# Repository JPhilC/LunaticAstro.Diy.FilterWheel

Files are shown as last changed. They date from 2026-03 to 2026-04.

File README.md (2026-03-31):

## An Arduino Nano controlled 3D printed filterwheel for astronomy.

This project was inspired by, and builds, on the work of chemistorge who's original repo can be found [here](https://github.com/chemistorge/Arduino-Motorised-Filter-Wheel-Xagyl-compatible-ASCOM-and-INDI-).

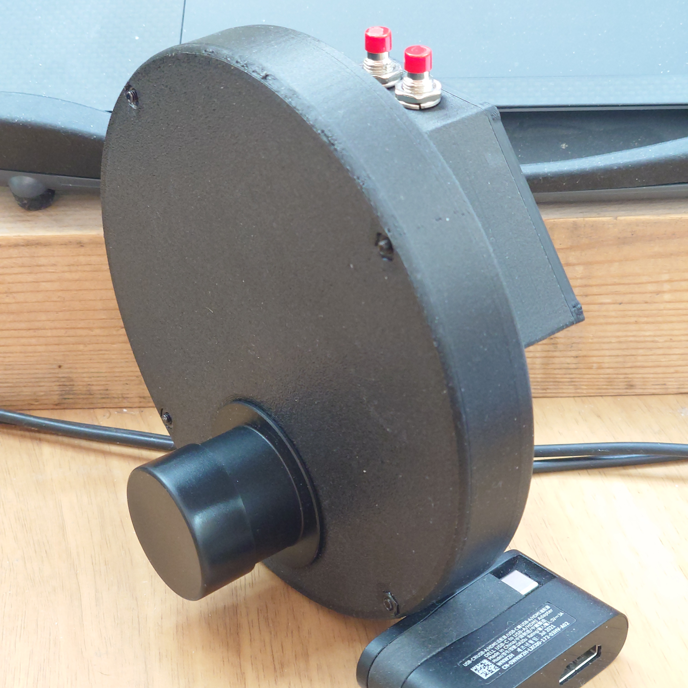
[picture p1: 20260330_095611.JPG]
Picture of front of filter wheel
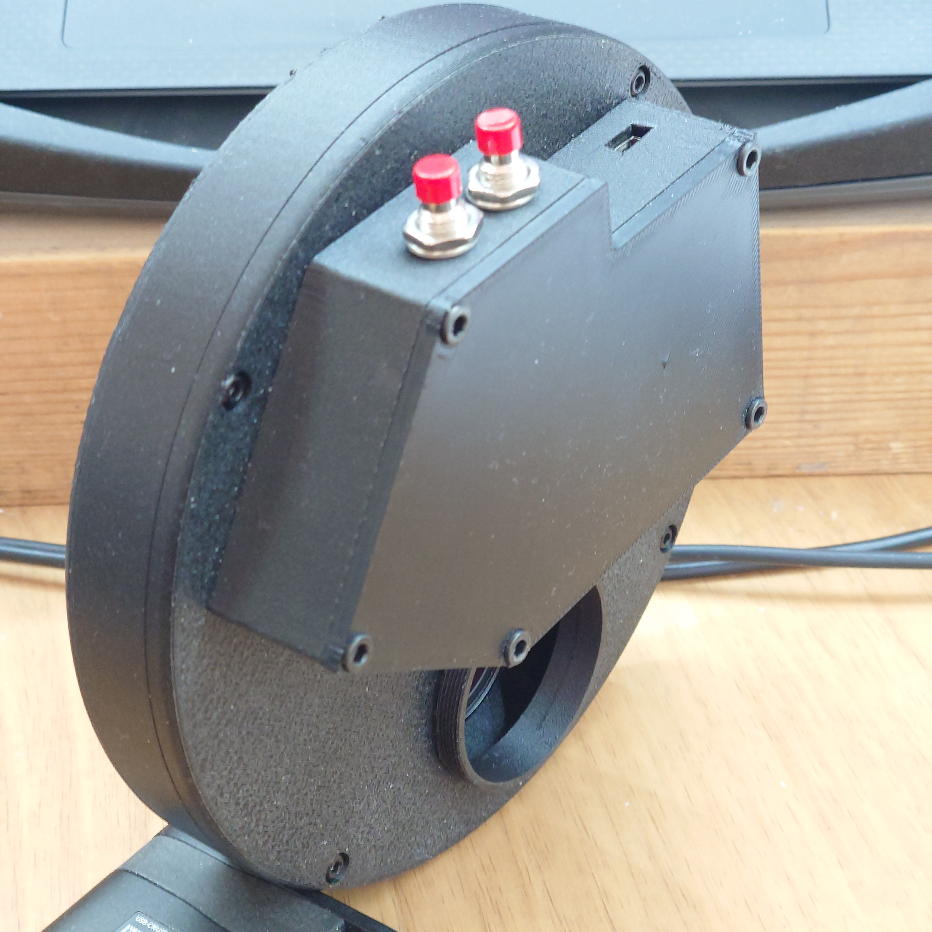
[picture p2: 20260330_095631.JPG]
Picture of back of filter wheel
|  |  |
|---|---|

After printing the parts I struggled to get the original firmware to operate reliably so I wrote new firmware, roughly based on the original but with improved home detection and button de-bounce code. I also changed the command set to make it more compatible with a new ASCOM driver that is also included in this project meaning that **the new firmware is not compatible with the old Xagly ASCOM driver**.

The firmware has only been tested with a unipolar 28BYJ-48 stepper motor, the common ULN2003 driver board and a KY-003 analogue hall sensor.

The original Xagly ASCOM driver appears not be supported or further developed so I wrote a new ASCOM driver that is better suited to the capabilities of the hardware.

The Ardiuno sketch is in the Firmware folder and the ASCOM source code is in the ASCOM Driver folder. 

The ASCOM drive passes ASCOMs Universal Conform tool and a log of the results is included in the ASCOM driver folder.

I printed my filter wheel parts in Sunlu PEG-CF on a Bambu A1 and will only be attaching my small ASI678 panetary camera.

## Disclaimer

The firmware and software in this project is provided “as is”, without warranty of any kind, express or implied.
The author shall not be held liable for any damages, loss of data, hardware damage,
or any other issues arising from the use of this software. Use at your own risk.
3D printed components can be weak along the layer lines so be sensible about what equipment you attach to the filter wheel.

## License

This project is licensed under the Creative Commons Attribution–NonCommercial 4.0 International License (CC BY-NC 4.0).

You may use, modify, and share the code for non-commercial purposes, provided you give appropriate credit.
Commercial use is strictly prohibited.

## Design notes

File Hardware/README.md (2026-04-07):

The hardware for this project is the same as [Arduino-Motorised-Filter-Wheel-Xagyl-compatible-ASCOM-and-INDI-](https://github.com/chemistorge/Arduino-Motorised-Filter-Wheel-Xagyl-compatible-ASCOM-and-INDI-). 

Rather than copying the details here, please refer to the original project for the original print files and also for details of the electrical components. 

## Important

The firmware in this project expects the following Arduino Nano pin outs:
### Analogue pins
- A1 - Hall sensor (common -)
- A2 - Hall sensor (power (centre pin on sensor))
- A3 - Hall sensor (sensor S)
### Digital pins
- 10 LED
- 4 Up button
- 5 Down button
- 6 Stepper IN2
- 7 Stepper IN4
- 8 Stepper IN3
- 9 Stepper IN1

## The Hall Sensor
The firmware has only been tested with a KY-003 analogue hall sensor. This is the one I used. This is the one I used [KY-003 Hall Effect Magnetic Sensor Module For Arduino](https://www.ebay.co.uk/itm/303361490827)

## Wiring internals
The image below shows the wiring and electronics prior to an LED being added.

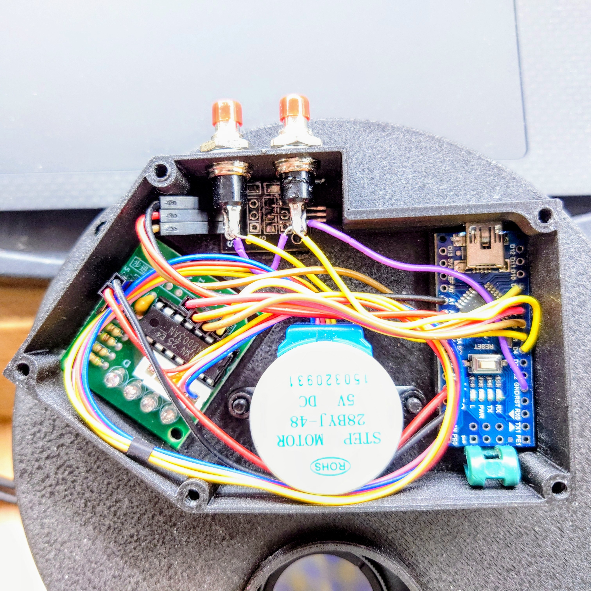
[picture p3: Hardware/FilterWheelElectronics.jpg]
Wiring internals


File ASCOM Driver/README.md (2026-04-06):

An ASCOM Driver for the Lunatic Astro DIY Filterwheel.

## The latest version of the ASCOM Driver
[**⬇️ Download Lunatic Astro Nano Filterwheel ASCOM Driver (MSI)**](./LunaticAstro.Nano.FilterWheel.Driver_V1.0.0.msi)

## Disclaimer
This software is provided “as is”, without warranty of any kind, express or implied. 
The author shall not be held liable for any damages, loss of data, hardware damage, 
or any other issues arising from the use of this software. Use at your own risk.

## License
This project is licensed under the Creative Commons Attribution–NonCommercial 4.0 International License (CC BY-NC 4.0).

You may use, modify, and share the code for non-commercial purposes, provided you give appropriate credit.
Commercial use is strictly prohibited.

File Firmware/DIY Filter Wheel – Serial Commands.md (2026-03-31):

# DIY Filter Wheel – Serial Command Reference
**Protocol Version 1.0**  
Compatible with Xagyl-style ASCOM drivers

This document describes the serial command protocol implemented by the DIY Filter Wheel firmware.  
The command set is intentionally compatible with the legacy Xagyl filter wheel protocol so that existing Xagyl ASCOM drivers can communicate with the device.

Commands fall into two categories:

- **Supported Commands** — These control real hardware behaviour.  
- **Spoofed Commands** — These return fixed or simulated values for Xagyl driver compatibility.  
  *(These may be removed or replaced when the custom ASCOM driver is complete.)*

---

# 1. Movement Commands

## **G1 .. G8 — Go To Filter Position**
**Syntax:** `Gn`  
Moves the wheel to filter position *n*.  
Filter **1** triggers a full homing cycle.

**Response:**
```text
P<n>
```

---

## **G0 — Save Configuration**
Saves all configuration settings (offsets, speed, etc.) to EEPROM.

**Response:**
```text
EEPROM Saved
```

---

# 2. Offset Commands

## **O1 .. O8 — Query Offset for Filter**
**Syntax:** `On`  
Returns the stored offset for filter *n*.

**Response:**
```text
P<n> Offset X
```

---

## **Fn xxxx — Set Positional Offset**
**Syntax:** `F<n> <number>`  
Sets the position offset for the filter in position `<n>` to an explicit value `<number>`. This allows you to centeralise the filter position in the filter wheel opening.  
Triggers a re-home and re-position.

**Response:**
```text
P<n> Offset X
```

---

# 3. Information Commands (Supported)

These map directly to `handleInfo(char c1)`.

## **I0 — Product Name**
**Response:**
```text
Nano Filter Wheel
```

---

## **I1 — Firmware Version**
**Response:**
```text
FW1.0.0
```

---

## **I2 — Current Filter Position**
**Response:**
```text
P<n>
```

---

## **I3 — Serial Number**
**Response:**
```text
DIY
```

---

## **I4 — Maximum Speed**
**Response:**
```text
MaxSpeed <maxSpeed>
```

---

## **I5 — Current Filter Offset**
**Response:**
```text
P<n> Offset X
```

---

## **I6 — Threshold**
**Response:**
```text
Threshold <analogSensorThreshold>
```

---

## **I7 — Number of Filter Slots**
**Response:**
```text
FilterSlots <numberOfFilters>
```

---

# 4. Sensor Test Commands

These map to `handleSensorTest(char c1)`.

## **T0 / T1 — Sensor Digital State**
**Response:**
```text
Sensors <state> <state>
```

---

## **T2 — Sensor Type**
**Response:**
```text
Digital YES
```
or
```text
Digital NO
```

---

## **T3 — Sensor Polarity**
**Response:**
```text
Active High YES
```
or
```text
Active High NO
```

---

# 5. Reset / Calibration Commands

These map to `handleReset(char c1)`.

## **R1 — Re-Initialise**
Re-initialises the wheel (calls `initialise()`).

---

## **R2 — Reset All Offsets**
Clears all offsets, saves configuration, and re-homes.

**Response:**
```text
Calibration Removed
```

---

## **R3 — Reset Speed to 100%**
**Response:**
```text
MaxSpeed 100%
```

---

## **R4 — Re-Detect Sensor and Re-Initialise**
**Response:**
```text
Threshold <analogSensorThreshold>
```

---

# 6. Speed Commands

## **Sxxx — Set Rotation Speed**
**Syntax:** `S<number>`  
Sets speed as a percentage of maximum.

**Response:**
```text
MaxSpeed <percent>%
```

---

## **T0 .. T3 — Sensor Test **
Returns values.

---

# 8. Unknown Commands
Unknown commands are silently ignored.

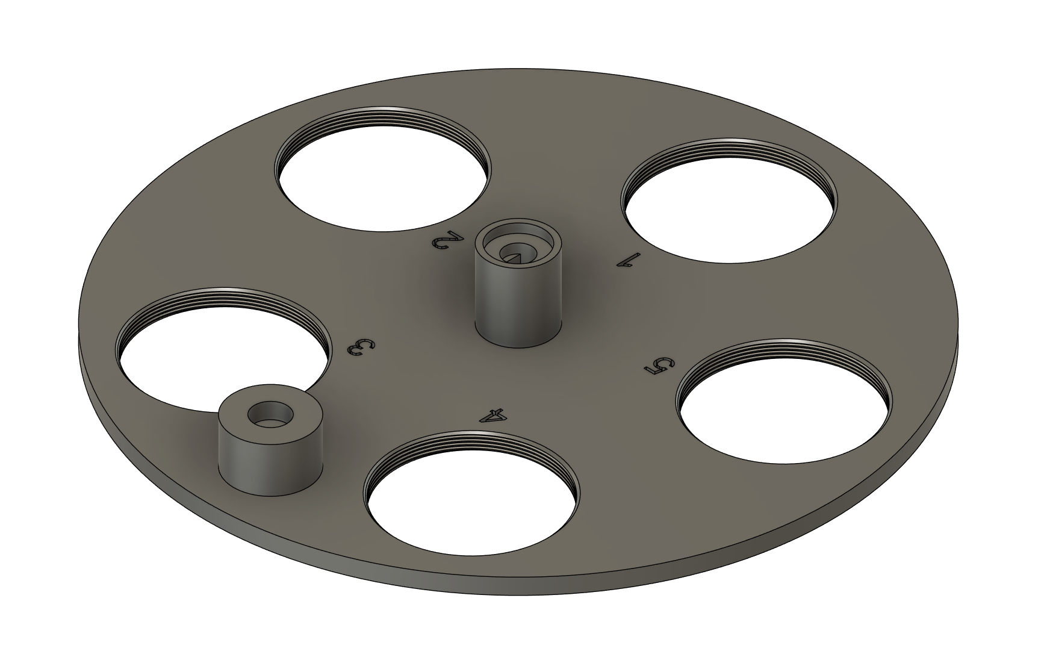
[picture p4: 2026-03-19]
Hardware/Wheel.png

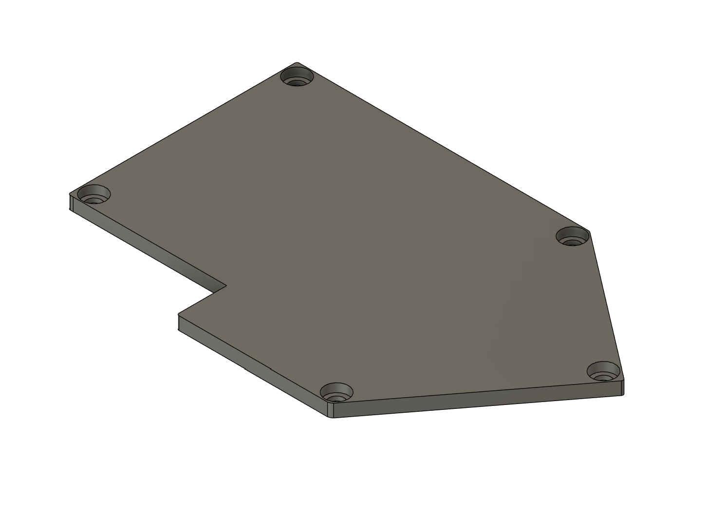
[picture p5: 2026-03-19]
Hardware/Cover.png

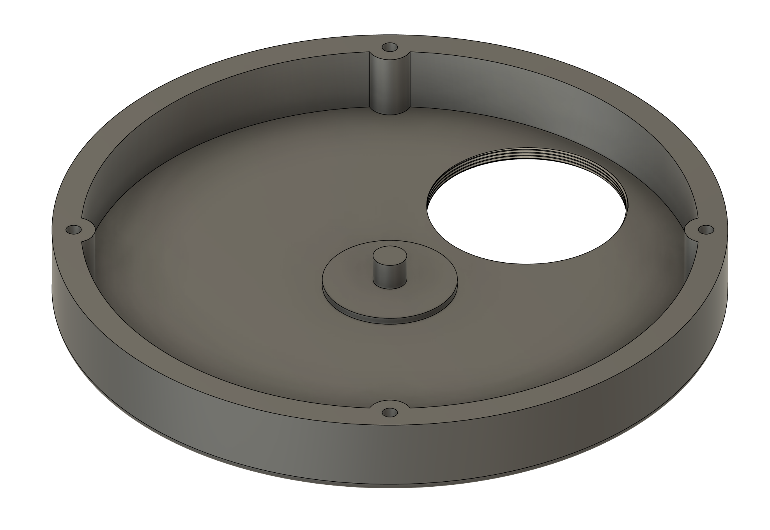
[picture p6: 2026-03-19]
Hardware/Bottom.png

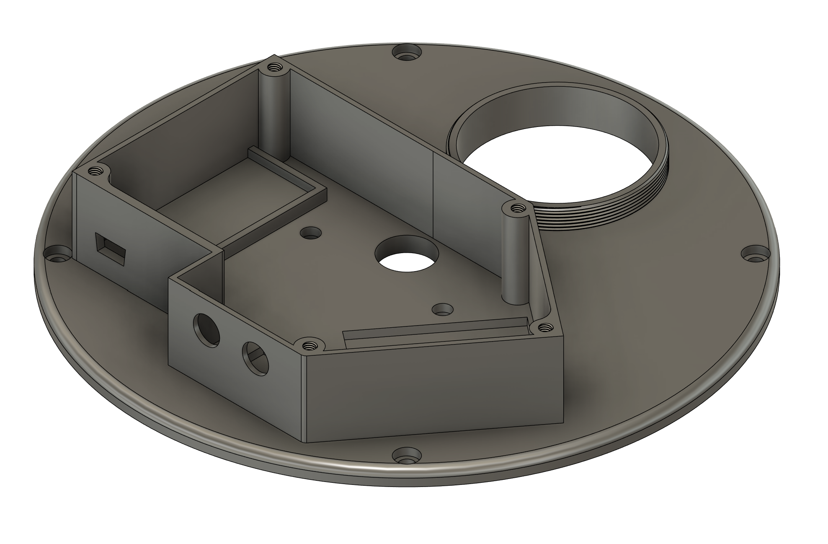
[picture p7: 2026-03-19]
Hardware/Top.png

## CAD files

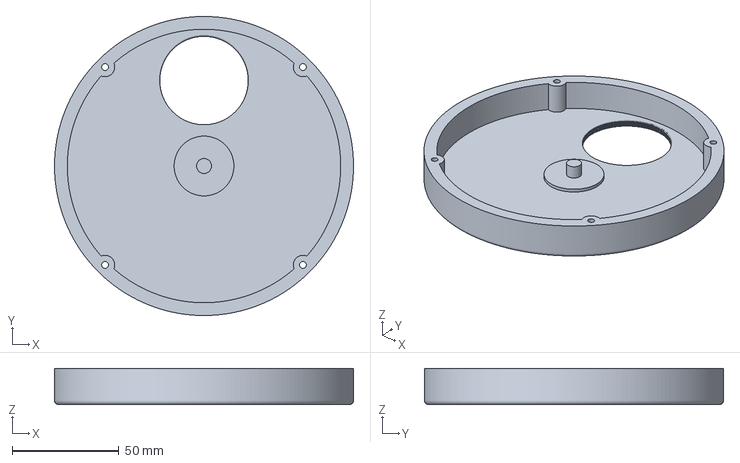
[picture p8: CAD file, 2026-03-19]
Hardware/Print Files/Bottom.3mf
140.0 x 140.0 x 17.0 mm

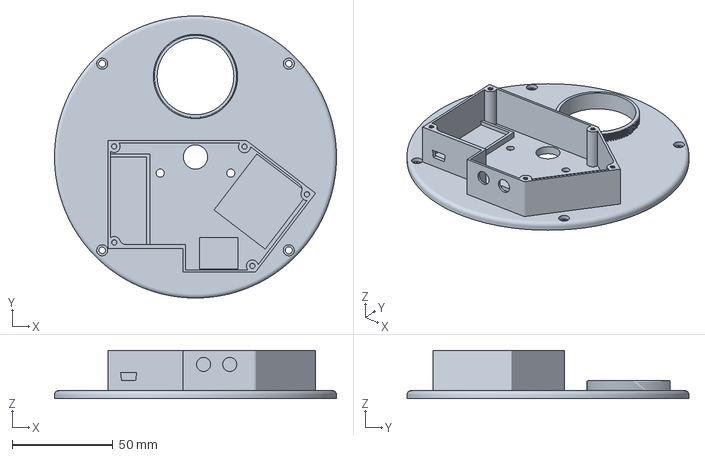
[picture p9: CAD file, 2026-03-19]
Hardware/Print Files/Top.3mf
140.0 x 140.0 x 24.0 mm

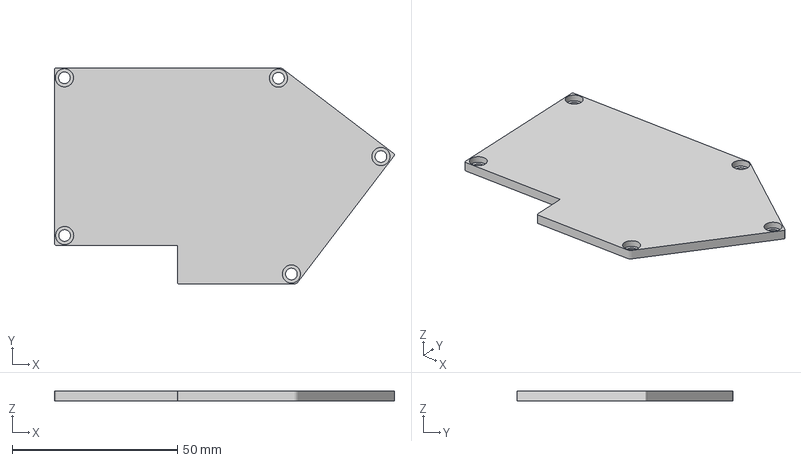
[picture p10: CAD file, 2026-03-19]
Hardware/Print Files/Cover.3mf
102.8 x 65.4 x 3.00 mm

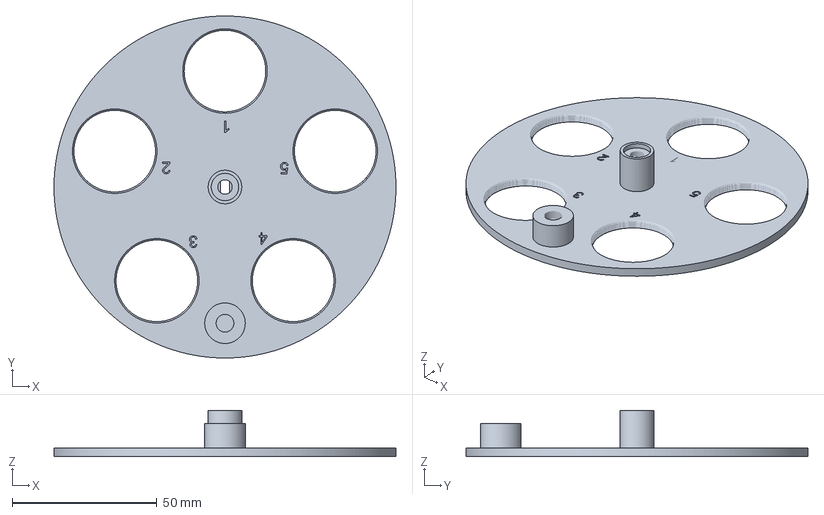
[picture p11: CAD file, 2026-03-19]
Hardware/Print Files/Wheel.3mf
118.0 x 118.0 x 16.0 mm

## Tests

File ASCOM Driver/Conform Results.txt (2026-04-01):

09:37:13.653 ASCOM Universal Device Conformance Checker Version 4.2.1.48140, Build time: Mon 09 February 2026 12:14:24
09:37:13.653 
09:37:13.654 Operating system is Windows 11 (25H2), Processor is Intel/AMD 64bit, Application is 64bit.
09:37:13.654 
09:37:13.654 COM Driver ProgID: ASCOM.LunaticAstroDiyFilterWheel.FilterWheel
09:37:13.654 
09:37:13.654 CreateDevice                        INFO     Creating NATIVE COM device: ASCOM.LunaticAstroDiyFilterWheel.FilterWheel
09:37:13.881 CreateDevice                        INFO     Successfully created driver
09:37:14.905 CreateDevice                        OK       Found a valid interface version: 3
09:37:14.906 CreateDevice                        OK       Driver instance created successfully
09:37:14.906 
09:37:14.906 Connect to device
09:37:16.427 Connected                           OK       Connected to device successfully using Connected = True
09:37:16.948 Connected                           OK       Disconnected from device successfully using Connected = False
09:37:18.964 Connect                             OK       Connected to device successfully using Connect()
09:37:18.964 
09:37:18.964 Common Driver Methods
09:37:18.964 InterfaceVersion                    OK       3
09:37:18.965 Connected                           OK       True
09:37:18.966 Description                         OK       Lunatic Astro Nano Filter Wheel
09:37:18.968 DriverInfo                          OK       Information about the driver itself. Version: 7.0
09:37:18.969 DriverVersion                       OK       7.0
09:37:18.969 Name                                OK       Lunatic Astro Nano Filter Wheel
09:37:18.969 
09:37:18.970 Action                              INFO     Conform cannot test the Action method
09:37:18.996 SupportedActions                    OK       Driver returned an empty action list
09:37:18.996 
09:37:19.006 DeviceState                         OK       Received 2 operational state properties.
09:37:19.007 DeviceState                         OK         Position = -1
09:37:19.007 DeviceState                         OK         TimeStamp = 01/04/2026 09:37:18
09:37:19.008 DeviceState                         OK       Found all expected operational properties
09:37:19.008 
09:37:19.008 Pre-run Checks
09:37:25.160 Pre-run Check                       OK       Filter wheel is stationary, ready to start tests
09:37:25.161 
09:37:25.161 Properties
09:37:25.162 FocusOffsets Get                    OK       Found 5 filter offset values
09:37:25.163 FocusOffsets Get                    INFO     Filter 0 Offset: 0
09:37:25.163 FocusOffsets Get                    INFO     Filter 1 Offset: 0
09:37:25.163 FocusOffsets Get                    INFO     Filter 2 Offset: 0
09:37:25.163 FocusOffsets Get                    INFO     Filter 3 Offset: 0
09:37:25.163 FocusOffsets Get                    INFO     Filter 4 Offset: 20
09:37:25.164 Names Get                           OK       Found 5 filter names
09:37:25.164 Names Get                           INFO     Filter 0 Name: Luminesence
09:37:25.164 Names Get                           INFO     Filter 1 Name: Red
09:37:25.164 Names Get                           INFO     Filter 2 Name: Green
09:37:25.165 Names Get                           INFO     Filter 3 Name: Blue
09:37:25.165 Names Get                           INFO     Filter 4 Name: <unused>
09:37:25.165 Names Get                           OK       Number of filter offsets and number of names are the same: 5
09:37:25.165 Position Get                        OK       Currently at position: 1
09:37:25.166 
09:37:25.166 Testing ascending sequential movement
09:37:25.285 Position Set 0                      OK       Reached position: 0 in: 0.1 seconds
09:37:27.719 Position Set 1                      OK       Reached position: 1 in: 1.4 seconds
09:37:30.137 Position Set 2                      OK       Reached position: 2 in: 1.4 seconds
09:37:32.557 Position Set 3                      OK       Reached position: 3 in: 1.4 seconds
09:37:34.985 Position Set 4                      OK       Reached position: 4 in: 1.4 seconds
09:37:36.000 
09:37:36.000 Testing descending sequential movement
09:37:36.113 Position Set 4                      OK       Reached position: 4 in: 0.1 seconds
09:37:39.942 Position Set 3                      OK       Reached position: 3 in: 2.8 seconds
09:37:43.663 Position Set 2                      OK       Reached position: 2 in: 2.7 seconds
09:37:47.493 Position Set 1                      OK       Reached position: 1 in: 2.8 seconds
09:37:51.310 Position Set 0                      OK       Reached position: 0 in: 2.8 seconds
09:37:52.322 
09:37:52.322 Testing potentially long distance moves
09:37:52.435 Position Set 0                      OK       Reached position: 0 in: 0.1 seconds
09:37:57.959 Position Set 4                      OK       Reached position: 4 in: 4.5 seconds
09:38:01.791 Position Set 3                      OK       Reached position: 3 in: 2.8 seconds
09:38:07.622 Position Set 0                      OK       Reached position: 0 in: 4.8 seconds
09:38:11.142 Position Set 2                      OK       Reached position: 2 in: 2.5 seconds
09:38:15.973 Position Set 0                      OK       Reached position: 0 in: 3.8 seconds
09:38:16.979 
09:38:16.979 Testing error conditions
09:38:17.009 Position Set                        OK       Correctly rejected bad position: -1
09:38:17.011 Position Set                        OK       Correctly rejected bad position: 5
09:38:17.011 
09:38:17.011 Directionality assessment
09:38:17.012 Directionality                      INFO     The filter wheel is uni-directional.
09:38:17.012 
09:38:17.012 Disconnect from device
09:38:17.526 Disconnect                          OK       Disconnected from device successfully using Disconnect()
09:38:17.526 
09:38:17.526 Conformance test has finished
09:38:17.526 
09:38:17.526 Congratulations, no errors, warnings or issues found: your driver passes ASCOM validation!!
09:38:17.526  
09:38:17.526 Timing Summary                               See Help for further information.
09:38:17.527 Timing Summary                               FAST target response time: 0.1 seconds, (configuration and state reporting members).
09:38:17.527 Timing Summary                               STANDARD target response time: 1.0 second, (property write and asynchronous initiators).
09:38:17.527 Timing Summary                               EXTENDED target response time: 600.0 seconds, (synchronous methods, ImageArray and ImageArrayVariant).
09:38:17.527 Timing Summary                               Conform is configured to report both good and bad timing outcomes.
09:38:17.527 
09:38:17.527 Connect                                      At 09:37:16.948 Connect                  0.001 seconds. ✓ (STANDARD)
09:38:17.527 InterfaceVersion                             At 09:37:18.964 InterfaceVersion         0.000 seconds. ✓ (FAST)
09:38:17.527 Connected                                    At 09:37:18.965 Connected                0.000 seconds. ✓ (FAST)
09:38:17.527 Description                                  At 09:37:18.966 Description              0.001 seconds. ✓ (FAST)
09:38:17.528 DriverInfo                                   At 09:37:18.967 DriverInfo               0.001 seconds. ✓ (FAST)
09:38:17.528 DriverVersion                                At 09:37:18.969 DriverVersion            0.001 seconds. ✓ (FAST)
09:38:17.528 Name                                         At 09:37:18.969 Name                     0.000 seconds. ✓ (FAST)
09:38:17.528 SupportedActions                             At 09:37:18.996 SupportedActions         0.026 seconds. ✓ (FAST)
09:38:17.528 DeviceState                                  At 09:37:19.006 DeviceState              0.010 seconds. ✓ (FAST)
09:38:17.528 FocusOffsets                                 At 09:37:25.162 FocusOffsets             0.001 seconds. ✓ (FAST)
09:38:17.528 Names                                        At 09:37:25.164 Names                    0.001 seconds. ✓ (FAST)
09:38:17.528 Position                                     At 09:37:25.165 Position                 0.001 seconds. ✓ (FAST)
09:38:17.528 Move to position 0                           At 09:37:25.172 Move to position 0       0.006 seconds. ✓ (STANDARD)
09:38:17.528 Move to position 1                           At 09:37:26.300 Move to position 1       0.002 seconds. ✓ (STANDARD)
09:38:17.529 Move to position 2                           At 09:37:28.733 Move to position 2       0.002 seconds. ✓ (STANDARD)
09:38:17.529 Move to position 3                           At 09:37:31.151 Move to position 3       0.001 seconds. ✓ (STANDARD)
09:38:17.529 Move to position 4                           At 09:37:33.567 Move to position 4       0.001 seconds. ✓ (STANDARD)
09:38:17.529 Move to position 4                           At 09:37:36.001 Move to position 4       0.001 seconds. ✓ (STANDARD)
09:38:17.529 Move to position 3                           At 09:37:37.125 Move to position 3       0.002 seconds. ✓ (STANDARD)
09:38:17.529 Move to position 2                           At 09:37:40.954 Move to position 2       0.001 seconds. ✓ (STANDARD)
09:38:17.529 Move to position 1                           At 09:37:44.675 Move to position 1       0.001 seconds. ✓ (STANDARD)
09:38:17.529 Move to position 0                           At 09:37:48.505 Move to position 0       0.001 seconds. ✓ (STANDARD)
09:38:17.530 Move to position 0                           At 09:37:52.323 Move to position 0       0.001 seconds. ✓ (STANDARD)
09:38:17.530 Move to position 4                           At 09:37:53.445 Move to position 4       0.002 seconds. ✓ (STANDARD)
09:38:17.530 Move to position 3                           At 09:37:58.977 Move to position 3       0.001 seconds. ✓ (STANDARD)
09:38:17.530 Move to position 0                           At 09:38:02.802 Move to position 0       0.001 seconds. ✓ (STANDARD)
09:38:17.530 Move to position 2                           At 09:38:08.627 Move to position 2       0.001 seconds. ✓ (STANDARD)
09:38:17.530 Move to position 0                           At 09:38:12.157 Move to position 0       0.001 seconds. ✓ (STANDARD)
09:38:17.530 Disconnect                                   At 09:38:17.013 Disconnect               0.001 seconds. ✓ (STANDARD)
09:38:17.530 
09:38:17.530 Congratulations, all members returned within their target response times!!

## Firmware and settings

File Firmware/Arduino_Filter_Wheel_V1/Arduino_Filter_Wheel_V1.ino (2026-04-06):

#include <AccelStepper.h>
#include <EEPROM.h>

/* ==========================================================================  
   Lunatic Astro Filter Wheel Firmware  
   Copyright © 2026 Phil Crompton, Lunatic Astro  
   All rights reserved.

   This firmware is provided for use with Lunatic Astro hardware projects.  
   Redistribution or modification is permitted only with explicit permission  
   from the copyright holder.

   For project information, updates, and documentation, visit Lunatic Astro.  
   ========================================================================== */


// =========================================================
// CONFIGURATION
// =========================================================

#define DEBUG 0  // Set to 1 for verbose debug output
#define FIRMWARE_VERSION "2.0"
// Pins
#define SENSOR A3
#define hallPower A2
#define hallCom A1
#define upButton 4
#define downButton 5
#define ledPin 10

// Motor pins (28BYJ-48 + ULN2003)
#define IN1 9
#define IN2 6
#define IN3 8
#define IN4 7

// Motor settings
#define maxSpeed 400
#define Speed 400
#define setAccel 1000
#define stepsPerRevolution 2048

// Filter wheel settings
#define MAX_FILTERS 8
#define NAME_SLOT_SIZE 31

#define offSetResolution 5
#define backlashOvershoot 200
#define SENSOR_OFFSET 70


// Optional peripherals
#define ledConnected 1

// Motor type (fixed)
#define motorType 1  // 1 = unipolar 28BYJ-48

// =========================================================
// GLOBALS
// =========================================================

#if motorType == 1
AccelStepper stepper(4, IN2, IN4, IN1, IN3);
#endif

int numberOfFilters = 5;
int filterPos[MAX_FILTERS + 1];
int16_t posOffset[MAX_FILTERS + 1];

bool Error = false;
int currPos = 0;

// Sensor characteristics (EEPROM-backed)
bool sensorIsDigital = false;
bool activeHigh = true;
int analogSensorThreshold = 650;
char filterNames[MAX_FILTERS + 1][NAME_SLOT_SIZE];
const char DEFAULT_FILTER_NAME[] = "<empty>";

// LED flash state machine
unsigned long ledLastToggle = 0;
int ledFlashCount = 0;
int ledFlashTarget = 0;
int ledInterval = 0;
bool ledState = false;
bool ledActive = false;


// =========================================================
// EEPROM HELPERS
// =========================================================

// EEPROM addresses
#define EE_THRESH 10
#define EE_DIGITAL 12
#define EE_ACTIVEHIGH 13
#define EE_OFFSET_BASE 52
#define EE_NAME_BASE (EE_OFFSET_BASE + (MAX_FILTERS * 2))  // 52 + 16 = 68


void writeInt(int addr, int value) {
  EEPROM.write(addr, value >> 8);
  EEPROM.write(addr + 1, value & 0xFF);
}

int readInt(int addr) {
  return (EEPROM.read(addr) << 8) | EEPROM.read(addr + 1);
}

void writeStringFixed(int addr, const char *str, int maxLen) {
  for (int i = 0; i < maxLen; i++) {
    char c = str[i];
    if (c == '\0') {
      EEPROM.write(addr + i, 0);
      // Fill the rest with 0
      for (int j = i + 1; j < maxLen; j++)
        EEPROM.write(addr + j, 0);
      return;
    }
    EEPROM.write(addr + i, c);
  }
}

void readStringFixed(int addr, char *buffer, int maxLen) {
  for (int i = 0; i < maxLen; i++) {
    buffer[i] = EEPROM.read(addr + i);
    if (buffer[i] == 0) {
      return;
    }
  }
  buffer[maxLen - 1] = 0;  // ensure null termination
}


void saveSensorSettings() {
  writeInt(EE_THRESH, analogSensorThreshold);
  EEPROM.write(EE_DIGITAL, sensorIsDigital ? 1 : 0);
  EEPROM.write(EE_ACTIVEHIGH, activeHigh ? 1 : 0);
  if (DEBUG) Serial.println("Sensor settings saved.");
}

// Save configuration settings
void saveConfigSettings() {

  // --- Save number of filters ---
  EEPROM.write(20, numberOfFilters);

  // --- Save offsets dynamically ---
  for (int i = 1; i <= numberOfFilters; i++) {
    int16_t raw = posOffset[i];  // must be unsigned
    EEPROM.write(EE_OFFSET_BASE + (i - 1) * 2, highByte(raw));
    EEPROM.write(EE_OFFSET_BASE + (i - 1) * 2 + 1, lowByte(raw));
  }

  // --- Save filter names ---
  for (int i = 1; i <= numberOfFilters; i++) {
    int addr = EE_NAME_BASE + (i - 1) * NAME_SLOT_SIZE;
    writeStringFixed(addr, filterNames[i], NAME_SLOT_SIZE);
  }

  if (DEBUG) Serial.println("Calibration settings saved.");
}

bool loadSensorSettings() {
  int t = readInt(EE_THRESH);
  int d = EEPROM.read(EE_DIGITAL);
  int a = EEPROM.read(EE_ACTIVEHIGH);

  // Validate
  if (t < 0 || t > 1023) return false;  // <-- widened range
  if (d != 0 && d != 1) return false;
  if (a != 0 && a != 1) return false;

  analogSensorThreshold = t;
  sensorIsDigital = d;
  activeHigh = a;

  if (DEBUG) {
    Serial.println("Loaded sensor settings from EEPROM:");
    Serial.print("Threshold=");
    Serial.println(analogSensorThreshold);
    Serial.print("Digital=");
    Serial.println(sensorIsDigital);
    Serial.print("ActiveHigh=");
    Serial.println(activeHigh);
  }

  return true;
}

void loadConfigSettings() {

  // --- Load number of filters ---
  numberOfFilters = EEPROM.read(20);

  // Validate range (3–8)
  if (numberOfFilters < 3 || numberOfFilters > 8) {
    numberOfFilters = 5;  // sensible default
  }

  // --- Initialise arrays to safe defaults ---
  for (int i = 1; i <= MAX_FILTERS; i++) {
    posOffset[i] = 0;
    filterPos[i] = 0;
  }

  // --- Compute ideal filter positions ---
  int stepsPerSlot = stepsPerRevolution / numberOfFilters;

  for (int i = 1; i <= numberOfFilters; i++) {
    filterPos[i] = (i - 1) * stepsPerSlot + SENSOR_OFFSET;
  }

  // --- Load offsets dynamically ---
  for (int i = 1; i <= numberOfFilters; i++) {
    uint8_t hi = EEPROM.read(EE_OFFSET_BASE + (i - 1) * 2);
    uint8_t lo = EEPROM.read(EE_OFFSET_BASE + (i - 1) * 2 + 1);
    int16_t val = word(hi, lo);

    // Detect uninitialised or absurd values
    if (val == 0x7FFF || val < -1000 || val > 1000) {
      val = 0;
    }


    posOffset[i] = val;
  }

  // --- Load filter names ---
  for (int i = 1; i <= numberOfFilters; i++) {
    int addr = EE_NAME_BASE + (i - 1) * NAME_SLOT_SIZE;
    readStringFixed(addr, filterNames[i], NAME_SLOT_SIZE);

    // Detect uninitialised or blank names
    if (filterNames[i][0] == 0xFF || filterNames[i][0] == 0) {
      // Set default
      strncpy(filterNames[i], DEFAULT_FILTER_NAME, NAME_SLOT_SIZE - 1);
      filterNames[i][NAME_SLOT_SIZE - 1] = 0;

      // Write back to EEPROM so it's persistent
      writeStringFixed(addr, filterNames[i], NAME_SLOT_SIZE);
    }
  }

  // --- Debug output ---
  if (DEBUG) {
    Serial.println("Loaded config settings from EEPROM:");
    Serial.print("Number of filters: ");
    Serial.println(numberOfFilters);

    for (int i = 1; i <= numberOfFilters; i++) {
      Serial.print("Offset[");
      Serial.print(i);
      Serial.print("] = ");
      Serial.println(posOffset[i]);

      Serial.print("Ideal FilterPos[");
      Serial.print(i);
      Serial.print("] = ");
      Serial.println(filterPos[i]);
    }

    for (int i = 1; i <= numberOfFilters; i++) {
      Serial.print("Name[");
      Serial.print(i);
      Serial.print("] = ");
      Serial.println(filterNames[i]);
    }
  }
}



// =========================================================
// SENSOR AUTO-DETECT
// =========================================================

void detectSensorType() {
  if (DEBUG) Serial.println("Sensor → running auto-detect…");

  int v, minVal = 1023, maxVal = 0;

  delay(50);

  // Back off to clear magnet
  stepper.runToNewPosition(stepper.currentPosition() - 1000);

  // Sweep one full revolution
  stepper.setAcceleration(setAccel);
  stepper.setMaxSpeed(maxSpeed);
  stepper.setSpeed(Speed);

  long target = stepper.currentPosition() + stepsPerRevolution;
  stepper.moveTo(target);

  while (stepper.distanceToGo() != 0) {
    stepper.run();
    v = analogRead(SENSOR);
    if (v < minVal) minVal = v;
    if (v > maxVal) maxVal = v;
  }

  if (DEBUG) Serial.println("min=" + String(minVal) + " max=" + String(maxVal));


  // Digital detection
  if (minVal < 50 || maxVal > 970) {
    sensorIsDigital = true;
    activeHigh = (maxVal > 970);
    Serial.println("Sensor is DIGITAL");
  } else {
    sensorIsDigital = false;
    activeHigh = (maxVal > minVal);

    // *** UPDATED THRESHOLD MARGIN ***
    analogSensorThreshold = activeHigh ? (maxVal - 40) : (minVal + 40);

    if (DEBUG) {
      Serial.println("Sensor is ANALOG");
      Serial.print("Polarity: active ");
      Serial.println(activeHigh ? "HIGH" : "LOW");
      Serial.println("Threshold " + String(analogSensorThreshold));
    }
  }

  // Rewind
  stepper.runToNewPosition(stepper.currentPosition() - stepsPerRevolution);
  stepper.setCurrentPosition(0);

  saveSensorSettings();
}
// =========================================================
// LED
// =========================================================
void startLedFlash(int flashes, int intervalMs) {
#if ledConnected
  ledActive = true;
  ledFlashCount = 0;
  ledFlashTarget = flashes * 2;  // ON+OFF = 2 toggles per flash
  ledInterval = intervalMs;
  ledLastToggle = millis();
  ledState = false;
  if (DEBUG) {
    Serial.println("LED LOW");
  }
  digitalWrite(ledPin, LOW);
#endif
}

void updateLed() {
#if ledConnected
  if (!ledActive) return;

  if (millis() - ledLastToggle >= ledInterval) {
    ledLastToggle = millis();
    ledState = !ledState;
    if (DEBUG) {
      Serial.print("LED: ");
      Serial.println(ledState);
    }
    digitalWrite(ledPin, ledState);

    ledFlashCount++;
    if (ledFlashCount >= ledFlashTarget) {
      ledActive = false;
      digitalWrite(ledPin, LOW);
      if (DEBUG) {
        Serial.println("LED: LOW");
      }
    }
  }
#endif
}


// =========================================================
// MOTOR + FEEDBACK HELPERS
// =========================================================

void motor_Off() {
  digitalWrite(IN1, LOW);
  digitalWrite(IN2, LOW);
  digitalWrite(IN3, LOW);
  digitalWrite(IN4, LOW);
}

// =========================================================
// HOMING
// =========================================================

bool homeWheel() {

  long safetyLimit = stepsPerRevolution * 2;
  long target;

  if (DEBUG) {
    Serial.println("=== HOMING START ===");
  }

  stepper.setAcceleration(setAccel);
  stepper.setMaxSpeed(maxSpeed);

  // ----------------------------------------------------
  // PHASE 1: Move until we are OFF the magnet
  // ----------------------------------------------------
  target = stepper.currentPosition() - safetyLimit;
  stepper.moveTo(target);

  while (stepper.distanceToGo() != 0) {
    stepper.run();

    int v = analogRead(SENSOR);
    bool triggered = activeHigh ? (v > analogSensorThreshold)
                                : (v < analogSensorThreshold);

    if (!triggered) {
      break;  // we are now OFF the magnet
    }
  }

  // Move a bit more to make sure
  target = stepper.currentPosition() - backlashOvershoot;
  stepper.moveTo(target);
  while (stepper.distanceToGo() != 0) {
    stepper.run();
  }


  // ----------------------------------------------------
  // PHASE 2: Now search for the magnet normally
  // ----------------------------------------------------
  // Continue in the SAME direction
  target = stepper.currentPosition() - safetyLimit;
  stepper.moveTo(target);

  while (stepper.distanceToGo() != 0) {
    stepper.run();

    int v = analogRead(SENSOR);
    bool triggered = activeHigh ? (v > analogSensorThreshold)
                                : (v < analogSensorThreshold);

    if (triggered) {
      stepper.stop();
      while (stepper.isRunning())
        stepper.run();

      stepper.setCurrentPosition(0);
      currPos = 0;

      if (DEBUG) Serial.println("Home found");
      return false;
    }
  }

  Serial.println("Home Sensor not found");
  return true;
}



// =========================================================
// MOVEMENT
// =========================================================

void goToLocation(int newPos, bool silent) {
  if (newPos < 1 || newPos > numberOfFilters) 
    return;
  
  if (DEBUG) {
    Serial.print("GoTo ");
    Serial.print(newPos);
    Serial.print(" filterPos[newPos] = ");
    Serial.print(filterPos[newPos]);
    Serial.print(" posOffset[newPos] = ");
    Serial.println(posOffset[newPos]);
  }

  if (newPos < currPos) {
    stepper.runToNewPosition(filterPos[newPos] + posOffset[newPos] - backlashOvershoot);
  }

  stepper.runToNewPosition(filterPos[newPos] + posOffset[newPos]);
  currPos = newPos;

  motor_Off();
  if (!silent) {
    Serial.println("P" + String(currPos));
  }
  startLedFlash(currPos, 120);  // N flashes, 120ms interval
}

void unwindBacklash() {
  stepper.runToNewPosition(stepper.currentPosition() - backlashOvershoot);
}

// =========================================================
// SERIAL PROTOCOL (unchanged from original)
// =========================================================

void sendSerial(String s) {
  Serial.println(s);
}


// =========================================================
// SETUP
// =========================================================

void setup() {
  Serial.begin(115200);

  pinMode(hallCom, OUTPUT);
  pinMode(hallPower, OUTPUT);
  pinMode(SENSOR, INPUT);
  pinMode(IN1, OUTPUT);
  pinMode(IN2, OUTPUT);
  pinMode(IN3, OUTPUT);
  pinMode(IN4, OUTPUT);
  pinMode(upButton, INPUT_PULLUP);
  pinMode(downButton, INPUT_PULLUP);
  pinMode(ledPin, OUTPUT);

  digitalWrite(hallCom, LOW);
  digitalWrite(hallPower, HIGH);
  digitalWrite(ledPin, LOW);
  sendSerial("CONNECTED");

  initialise();
}

// =========================================================
// LOOP
// =========================================================

void loop() {
  updateLed();
  handleButtons();
  handleSerialCommands();
  handleErrors();
}

void dispatchXagylCommand(const String &cmd) {

  if (cmd.length() == 0) return;

  char c0 = cmd.charAt(0);
  char c1 = cmd.length() > 1 ? cmd.charAt(1) : 0;

  switch (c0) {

    // ============================================================
    // GOTO FILTER (G1..G8)
    // ============================================================
    case 'G':
      if (c1 == '0') {
        // G0 = Save EEPROM
        saveConfigSettings();
        sendSerial("EEPROM Saved");
        return;
      } else {
        // G1..G8 = goto filter
        handleGoto(c1);
        return;
      }


    // ============================================================
    // OFFSET QUERY (O1..O8)
    // ============================================================
    case 'O':
      handleOffsetQuery(c1);
      return;


    // ============================================================
    // SET ABSOLUTE OFFSET (F<n> <xxxx>)
    // ============================================================
    case 'F':
      handleSetAbsoluteOffset(cmd);
      return;



    // ============================================================
    // NAME QUERY (Q1..Q8)
    // ============================================================
    case 'Q':
      handleNameQuery(cmd);
      return;


    // ============================================================
    // SET FILTER NAME (N<n> <cccccccccccccccccccccccccccccc>)
    // ============================================================
    case 'N':
      handleSetName(cmd);
      return;


    // ============================================================
    // INFORMATION COMMANDS (I0..I9)
    // ============================================================
    case 'I':
      handleInfo(c1);
      return;


    // ============================================================
    // SENSOR TEST COMMANDS (T0..T3)
    // ============================================================
    case 'T':
      handleSensorTest(c1);
      return;


    // ============================================================
    // RESET / CALIBRATION COMMANDS (R0..R6)
    // ============================================================
    case 'R':
      handleReset(c1);
      return;


    // ============================================================
    // SPEED SETTING (Sxxx)
    // ============================================================
    case 'S':
      handleSetSpeed(cmd);
      return;

      break;
  }

  // Unknown command → ignore silently (Xagyl behaviour)
}

// ============================
// COMMAND HANDLERS
// ============================
// --- Debounce state ---
const unsigned long debounceTime = 50;  // 50ms is ideal for mechanical buttons

unsigned long lastUpPress = 0;
unsigned long lastDownPress = 0;

bool lastUpState = HIGH;
bool lastDownState = HIGH;

void handleButtons() {

  // UP BUTTON
  bool upState = digitalRead(upButton);
  if (upState == LOW && lastUpState == HIGH) {
    unsigned long now = millis();
    if (now - lastUpPress > debounceTime) {

      if (currPos < numberOfFilters) {
        goToLocation(currPos + 1, false);
        sendSerial("P" + String(currPos));
      }
      else {
           startLedFlash(currPos, 120);
      }

      lastUpPress = now;
    }
  }
  lastUpState = upState;

  // DOWN BUTTON
  bool downState = digitalRead(downButton);
  if (downState == LOW && lastDownState == HIGH) {
    unsigned long now = millis();
    if (now - lastDownPress > debounceTime) {

      if (currPos > 1) {
        goToLocation(currPos - 1, false);
        sendSerial("P" + String(currPos));
      }
      else {
           startLedFlash(currPos, 120);
      }

      lastDownPress = now;
    }
  }
  lastDownState = downState;
}

void handleSerialCommands() {
  if (!Serial.available()) return;

  Serial.setTimeout(250);
  String cmd = Serial.readStringUntil('\n');

  if (cmd.length() == 0) return;

  dispatchXagylCommand(cmd);
}

void handleErrors() {
  if (Error) {
    Serial.println("Homing Failed");
    Error = false;
  }
}

// ============================
// OFFSET COMMAND HANDLERS
// ============================

void handleOffsetQuery(char c1) {
  int f = c1 - '0';
  if (f < 1 || f > numberOfFilters) return;

  sendSerial("P" + String(f) + " Offset " + String(posOffset[f]));
}

void handleSetAbsoluteOffset(const String &cmd) {
  // Expected format: "F<n> <offset>"
  // Example: "F3 120"

  // 1. Find the space separating filter number and offset
  int spaceIndex = cmd.indexOf(' ');
  if (spaceIndex < 0) {
    sendSerial("ERR Invalid Format");
    return;
  }

  // 2. Extract filter number
  int f = cmd.substring(1, spaceIndex).toInt();  // characters after 'F' up to space

  if (f < 1 || f > numberOfFilters) {
    sendSerial("ERR Invalid Filter");
    return;
  }

  // 3. Extract offset value
  int val = cmd.substring(spaceIndex + 1).toInt();

  // 4. Store offset
  posOffset[f] = val;
  writeInt(EE_OFFSET_BASE + (f - 1) * 2, posOffset[f]);

  // 5. Move wheel to new absolute position
  unwindAndGoto(f);

  // 6. Emit confirmation
  sendSerial("P" + String(f) + " Offset " + String(posOffset[f]));
}


void handleSetName(const String &cmd) {
  // cmd is the full command string, e.g. "L3 Red Filter"
  // First extract the slot number after 'L'

  int spaceIndex = cmd.indexOf(' ');
  if (spaceIndex == -1) {
    Serial.println("ERR Missing name");
    return;
  }


  // Extract slot number
  int slot = cmd.substring(1, spaceIndex).toInt();

  if (slot < 1 || slot > numberOfFilters) {
    Serial.println("ERR Slot out of range");
    return;
  }

  // Extract the name (everything after the first space)
  String newName = cmd.substring(spaceIndex + 1);

  // Trim whitespace
  newName.trim();

  // Enforce max length (30 chars)
  if (newName.length() > 30) {
    newName = newName.substring(0, 30);
  }

  // Copy into global array
  newName.toCharArray(filterNames[slot], NAME_SLOT_SIZE);

  // Save to EEPROM
  int addr = EE_NAME_BASE + (slot - 1) * NAME_SLOT_SIZE;
  writeStringFixed(addr, filterNames[slot], NAME_SLOT_SIZE);

  // Respond in protocol format
  Serial.print("P");
  Serial.print(slot);
  Serial.print(" Name ");
  Serial.println(filterNames[slot]);
}

void handleNameQuery(const String &cmd) {
  // cmd is the full command, e.g. "N3"
  // Extract the slot number after 'N'

  if (cmd.length() < 2) {
    Serial.println("ERR Missing slot");
    return;
  }

  int slot = cmd.substring(1).toInt();

  if (slot < 1 || slot > numberOfFilters) {
    Serial.println("ERR Slot out of range");
    return;
  }

  // Respond in protocol format:
  // P<n> Name <name>
  Serial.print("P");
  Serial.print(slot);
  Serial.print(" Name ");
  Serial.println(filterNames[slot]);
}

void handleGoto(char c1) {
  int f = c1 - '0';
  if (f < 1 || f > numberOfFilters) return;

  goToLocation(f, false);
}


void handleInfo(char c1) {
  switch (c1) {
    case '0': sendSerial("Lunatic Astro Nano Filter Wheel"); break;  // Product Name
    case '1': sendSerial(FIRMWARE_VERSION); break;                   // Firmware version
    case '2': sendSerial("P" + String(currPos)); break;              // Current filter position
    case '3': sendSerial("DIY"); break;                              // Serial number
    case '4': sendSerial("MaxSpeed " + String(maxSpeed)); break;     // Max speed
    case '5': sendOffsetReport(currPos); break;
    case '6': sendSerial("Threshold " + String(analogSensorThreshold)); break;
    case '7': sendSerial("FilterSlots " + String(numberOfFilters)); break;
  }
}


void handleSensorTest(char c1) {
  switch (c1) {
    case '0':
    case '1':
      sendSerial("Sensors " + String(digitalRead(SENSOR)) + " " + String(digitalRead(SENSOR)));
      break;

    case '2':
      sendSerial("Digital " + String(sensorIsDigital ? "YES" : "NO"));
      break;

    case '3':
      sendSerial("Active High " + String(activeHigh ? "YES" : "NO"));
      break;
  }
}
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

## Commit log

2026-03-19 Initial commit of combined repo.
    [Bottom.3mf, Cover.3mf, Top.3mf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]
2026-03-19 Update README with project details and references
    Expanded project description and added links to original firmware and ASCOM driver.
2026-03-19 Update Arduino_Filter_Wheel_V1.ino
    Tidying up offset handling and reading and writing calibration settings to EEPROM.
2026-03-20 Refined commands
    Refined the commands to just support those that the DIY hardware can support so no Jitter, PWM etc.
    [Arduino_Filter_Wheel_V1.ino]
2026-03-20 Create DIY Filter Wheel – Serial Commands.txt
    Add documentation for the commands supported by the firmware.
2026-03-20 Update DIY Filter Wheel – Serial Commands.md
2026-03-29 Adding ASCOM Driver Project
    Moved the ASCOM driver code into this repository so that everything for the FilterWheel project is under one repo.
2026-03-29 Update README with ASCOM driver details and disclaimer
    Clarified the description of the ASCOM driver and its inclusion in the repository. Updated the warranty disclaimer to include software.
2026-03-30 Create README.md for hardware specifications
    Added hardware details and pinout information for Arduino Nano.
2026-03-30 Revise README for clarity and sensor details
    Updated wording for clarity and added information about the Hall sensor.
2026-03-30 Create FilterWheelElectronics.jpg
    Added better picture of electronics (before LED added).
2026-03-30 Add wiring internals section to README
    Added wiring internals section with image reference.
2026-03-30 Update README with firmware and ASCOM driver details
    Rewrote sections for clarity and added details about firmware compatibility and new ASCOM driver.
2026-04-01 Update the setup dialog so that filter settings are written to the filterwheel as they are changed. This is better for adjust a filter's position. The cancel button on the setup dialog will now rever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
2026-04-06 Added LED functions to firmware
    Added control of an LED that will flash the filter number when the wheel has finished moving to a new position.
2026-04-06 Updated WiX to build with embedded cab. Also copied the release MSI to ASCOM Driver folder.
2026-04-06 Update README with download link for ASCOM Driver
    Added a download link for the latest version of the ASCOM Driver.
2026-04-07 Update LED pin count in README
